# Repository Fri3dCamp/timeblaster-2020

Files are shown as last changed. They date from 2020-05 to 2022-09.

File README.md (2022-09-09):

# Time Blaster

This repository contains the design files for the Time Blaster project part of Fri3d Camp 2020.

The design is based around an ATMega328p, some IR receivers and an IR LED.

The progress of this project can be followed on [Hackaday.io](https://hackaday.io/project/167668-time-blaster)

## Blockdiagram

In order to make the documentation easier to use, we've added the block diagram as well.

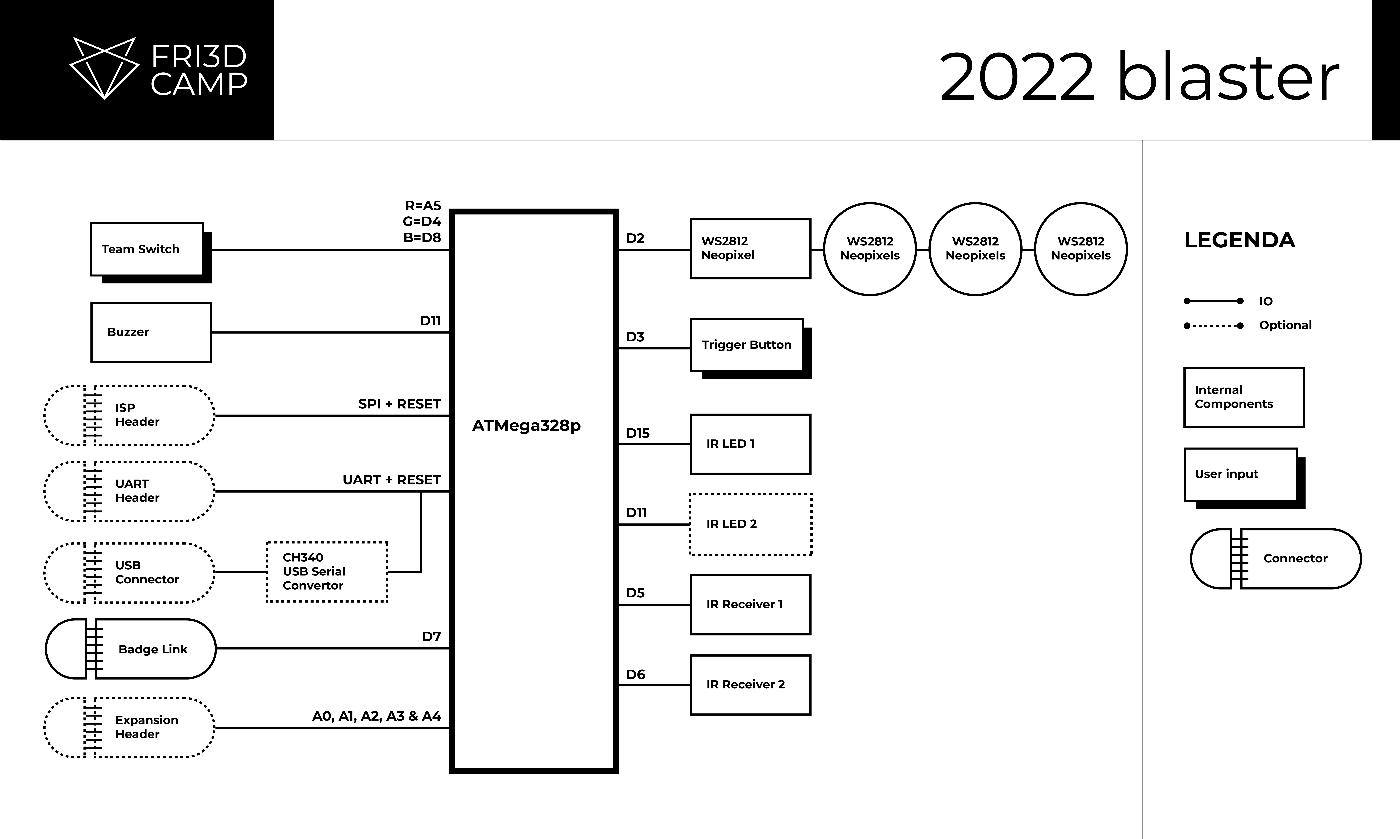
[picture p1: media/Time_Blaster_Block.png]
Time Blaster Block Diagram


## Hardware Revision 00

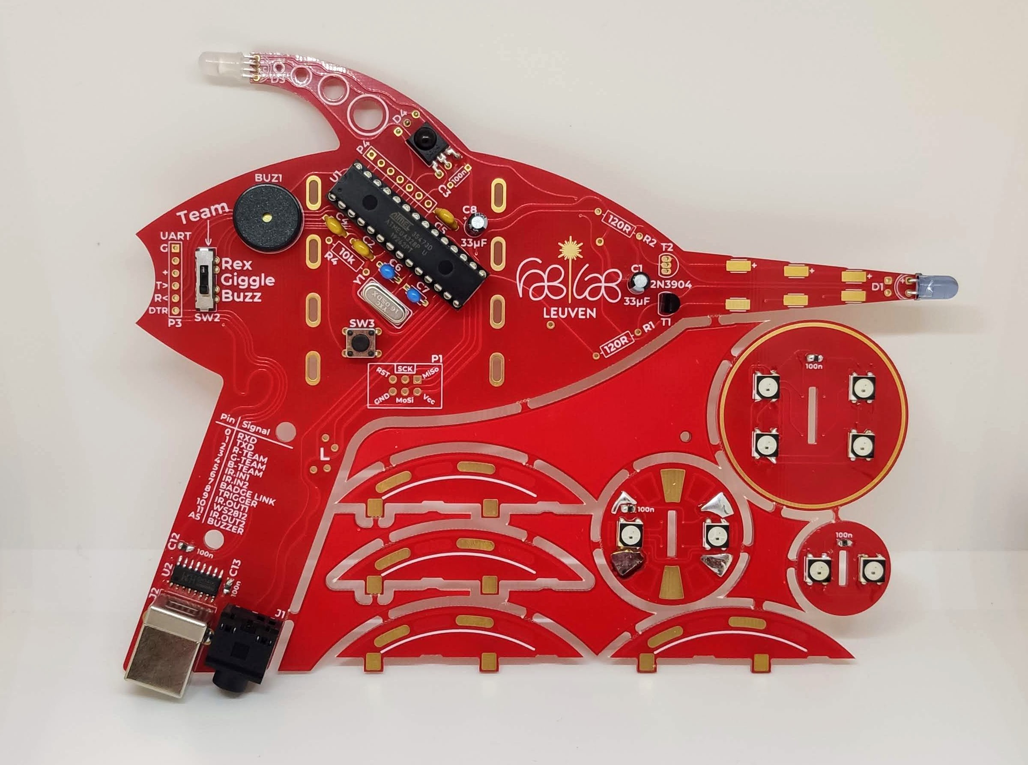
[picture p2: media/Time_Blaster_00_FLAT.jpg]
Time Blaster 00 Flat


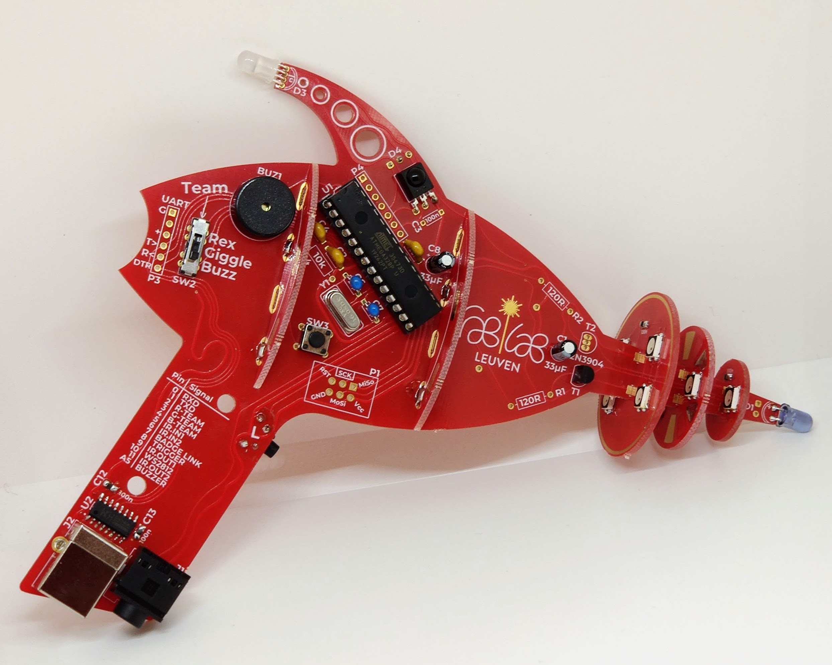
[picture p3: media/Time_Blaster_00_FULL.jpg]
Time Blaster 00 Full


## Hardware Revision 01

Added support for USB C and Micro USB. Fixed a bug with the USB Serial convertor, some pin swaps for firmware development.

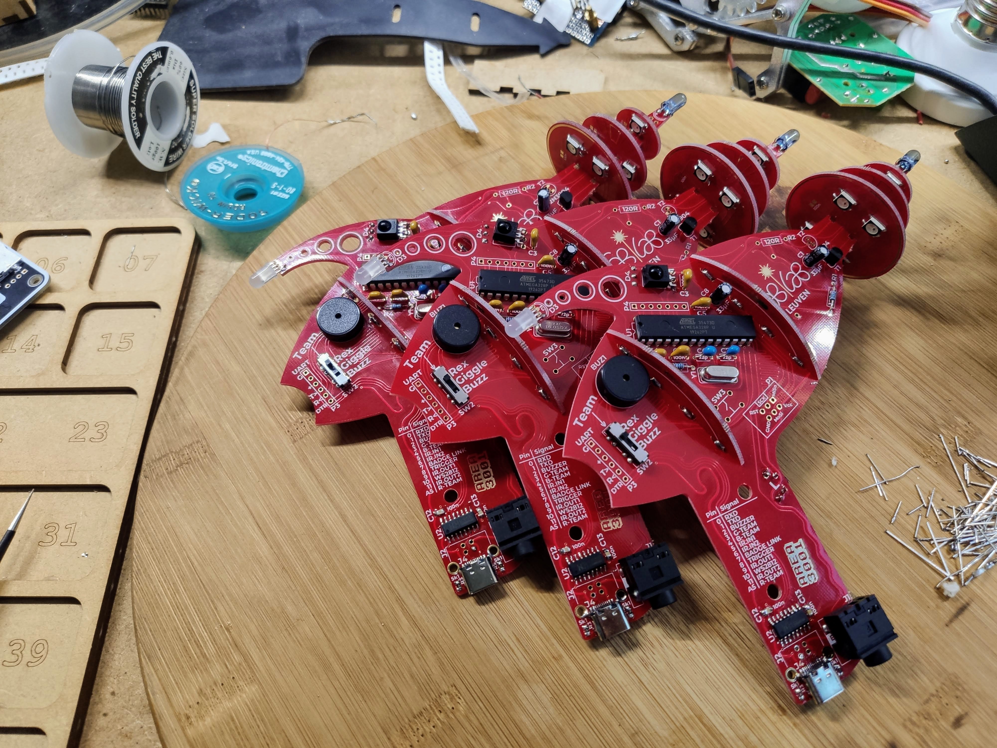
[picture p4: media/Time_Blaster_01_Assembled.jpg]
Time Blaster 01 Assembled


## Hardware Revision 02

Added a series resistor for the IR LEDs, this is only required when powering the device from 5V.

## Firmware

The default firmware (which has already been flashed on the MCU) can be found on the [Area 3001 Github page](https://github.com/area3001/Timeblaster).

# Assembly Instructions
The assembly instructions can also be found in the leaflets located in the "media" folder of this repository

## Resistor note
The 120Ω resistor has been marked with a red permanent marker since the color coding for the 120Ω and 10KΩ resistor are too similar

## Trigger switch
The side of the trigger switch can be chosen depending on left hand or right hand use case

## Team selection switch
Take note of silkscreen on the PCB for correct placement of the team selector switch. The switch has metal on 1 side, this side is also indicated on the PCB and should face the team names.

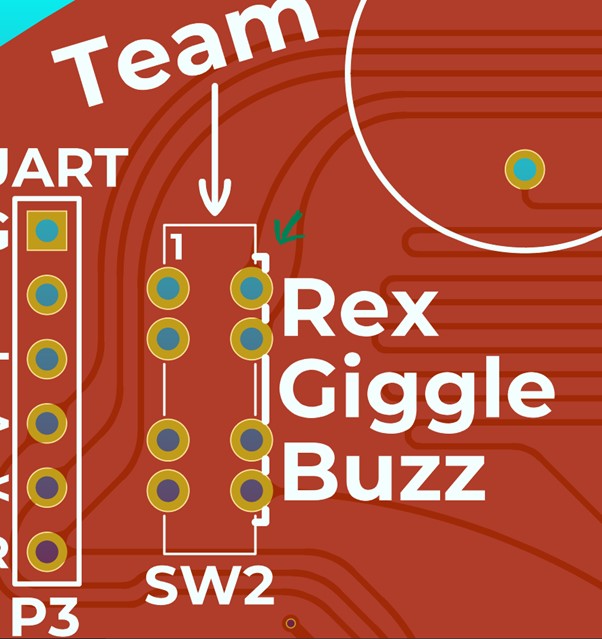
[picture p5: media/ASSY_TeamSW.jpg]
Time Blaster Assembly Team Switch Render


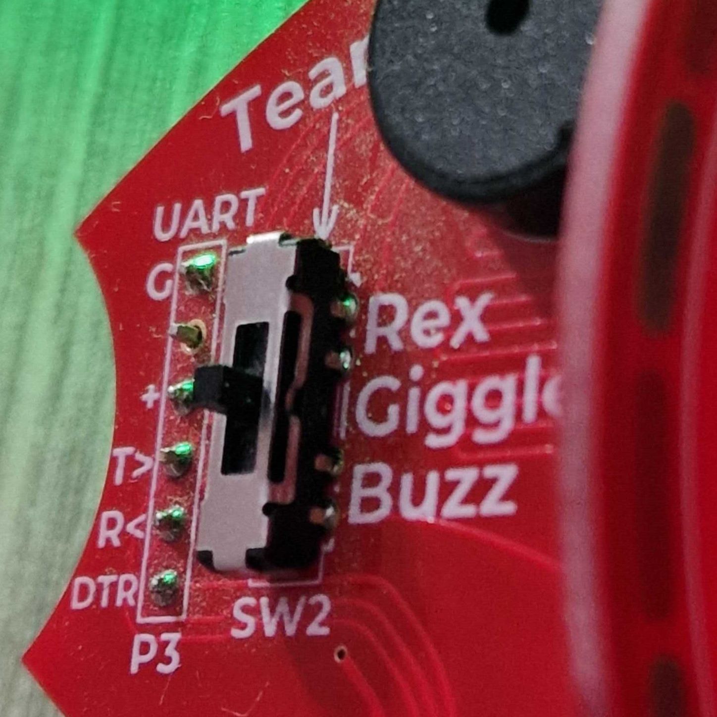
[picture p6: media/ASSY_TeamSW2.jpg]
Time Blaster Assembly Team Switch

 
## Microcontroller soldering note
Take care when mounting the ATMega328p microcontroller, don't heat up the pins too long to avoid damaging them. To avoid creating a hot spot, you can opt for alternating sides when soldering the pins.

## Ring mounting
Mount the rings with SMD LEDs before you solder the IR LED in place.

## LED Polarity
The IR LED has a small + polarity marking on the board, this is the hole for the long lead of the LED.

## Which components to mount
R1 120Ω, MOSFET T1, R6 33Ω and IR LED D1 should be mounted 

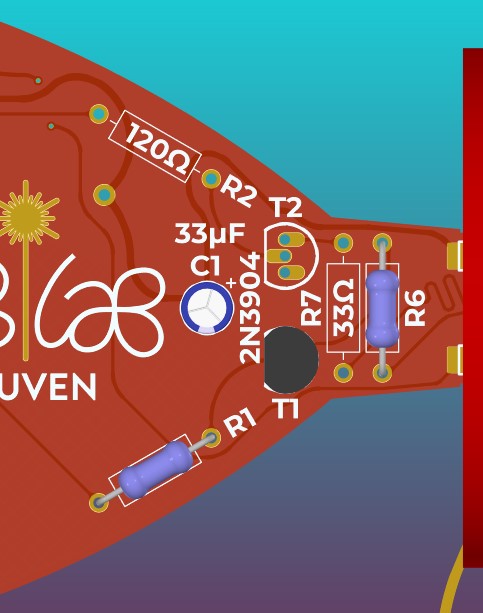
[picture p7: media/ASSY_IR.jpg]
Time Blaster Assembly IR

 
Capacitor C4 (100nF), push button SW3 and right angle connector P3 are optional for Arduino style programming over FTDI UART connection.

## USB
Optional USB circuitry kits based around the CH340 USB to serial convertor are available upon request. These kits include an USB connector (USB-B, USB-C or Micro USB), 2 capacitors and the CH340 chip. In case of the USB-C variant, there will also be 2 resistors of 5.1kΩ included.

# 3D Printable grip
Thomas Pilkington designed a 3D printable grip for the blaster which vastly improves the ergonomics of the blaster, especially for adults. These files can either be printed as-is or modified to your preference. The model contains cutouts for both left- and righthanded triggers and for the optional USB-B or USB-C connector. The guys from [KO-LAB](https://ko-lab.space/) slightly modified the design for better clearance, these v2 files can also be found in the grip directory.

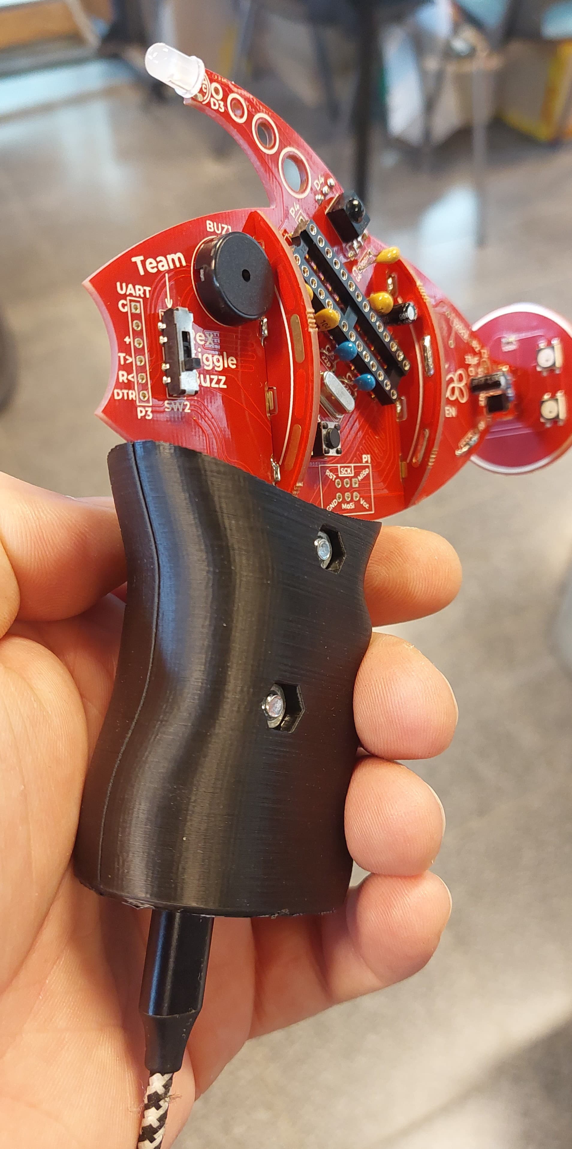
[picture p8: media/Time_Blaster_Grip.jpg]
Time Blaster with grip


# 3D Printable LED Protector
[Hans Polders](https://github.com/melazarus) designed a 3D printable IR LED protector so that it has less chance of bending and breaking.
It was designed in [OpenSCAD](https://openscad.org/), for which the source file is also available.

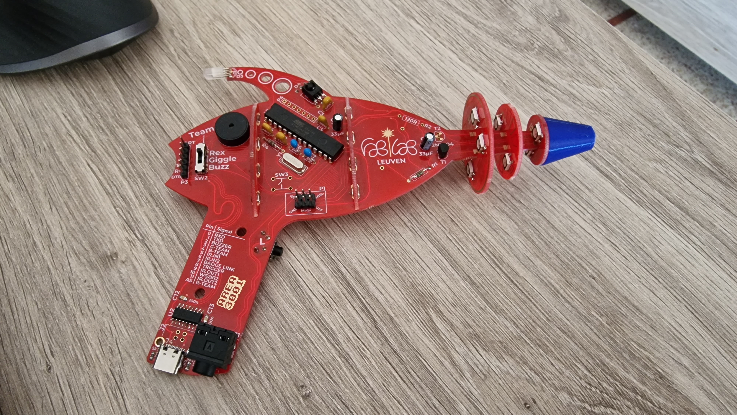
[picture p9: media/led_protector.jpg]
LED Protector

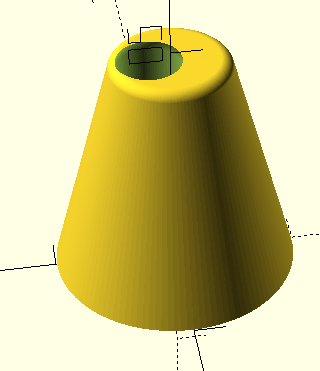
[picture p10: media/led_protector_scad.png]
LED Protector SCAD


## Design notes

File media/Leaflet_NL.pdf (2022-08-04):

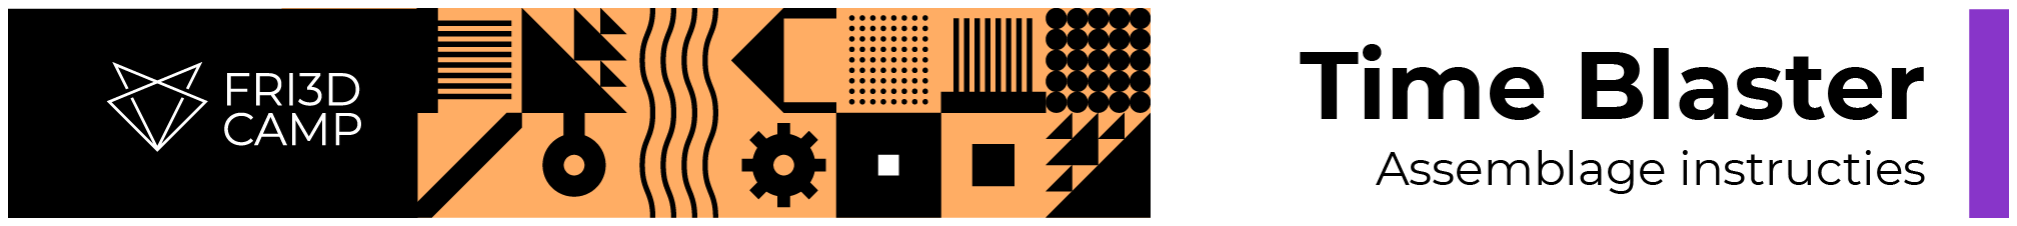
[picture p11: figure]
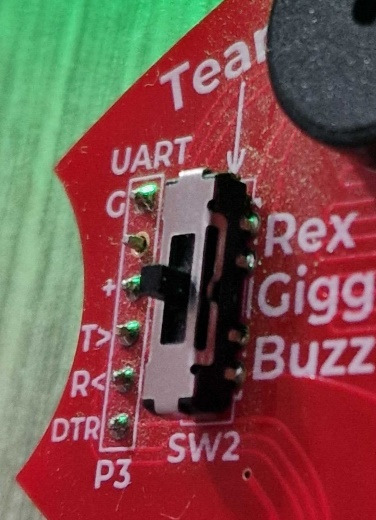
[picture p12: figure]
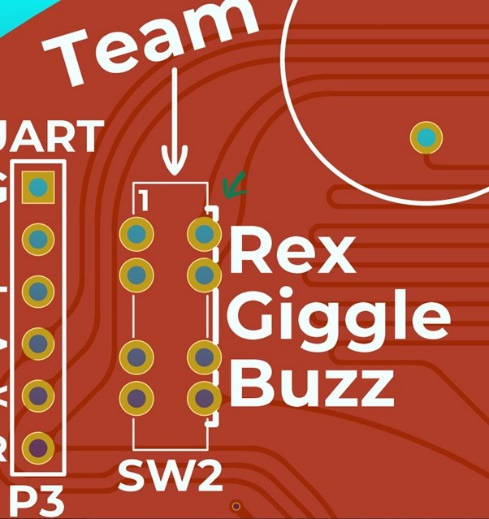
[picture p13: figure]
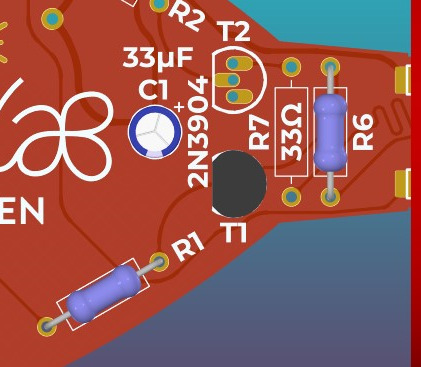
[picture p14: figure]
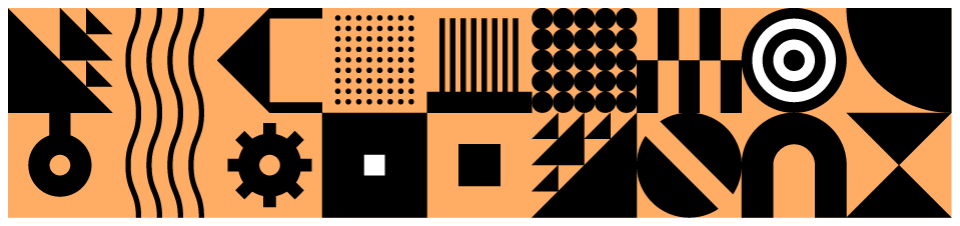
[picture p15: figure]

Wim Van Gool – 20220725 – Blaster NL Rev.02 https://github.com/Fri3dCamp/timeblaster-2020https://hackaday.io/project/167668-time-blasterhttps://fri3d.be/badge/

Inhoud
In de verpakking van de Time Blaster zal je deze handleiding, een printplaat, een kabel om de Blaster aan de badge aan te sluiten en een zakje boordevol componenten vinden. Ontbreekt een van deze zaken? Aarzel dan niet om even te informeren bij de infodesk.

Voor enkele van deze componenten is wat extra uitleg wel handig, vandaar deze handleiding.

“Rode” Weerstand
De 120Ω-weerstand is gemarkeerd met een rode permanent marker om verwarring te voorkomen aangezien de kleurcodes voor de 120Ω en 10KΩ gelijkaardig zijn.

“Trigger”-drukknop
Afhankelijk of je links- of rechtshandig
bent, kan je de drukknop SW1 aan de
correcte zijde van de printplaat monteren. Let hiervoor op de “L” of “R”.

Selectieschakelaar “Team”
Kijk goed naar de markering op de printplaat om de schakelaar correct te monteren. De schakelaar heeft een metalen lip aan 1 zijde. Deze zijde moet
richting de teamnamen staan.

!Soldeertip! Microcontroller
Wanneer je de ATMega328p-microcontroller gaat solderen zorg je er best voor dat de pinnen niet te lang warm zijn (om te voorkomen dat je deze component zou beschadigen). Uiteraard moet je nog wel een mooie uitvloeiing hebben van het soldeersel voor een correcte verbinding. Een optie om de hitte wat te verspreiden is het alternerend solderen van pinnen aan beide zijden.

Zorg dat je deze component correct oriënteert. Dit kan je zien aan de kleine U-vormige uitsparing op de chip die ook getekend is op de printplaat.

Welke componenten moet je solderen?
!Let op! Vooraan op de Blaster zijn er enkele
componenten die er 2x op staan. Transistor T1, IR LED D1, Weerstanden R1 120Ω en R6 33Ω moeten gesoldeerd worden. Zoals in de afbeelding hiernaast. T2, D2, R2 en R7 dienen niet bestukt te worden.

Verder zijn er ook nog optionele componenten: condensator C4 (100nF), drukknop SW3 en haakse connector P3. Deze zorgen ervoor dat je kan programmeren met de Arduino IDE via een FTDI UART kabel.

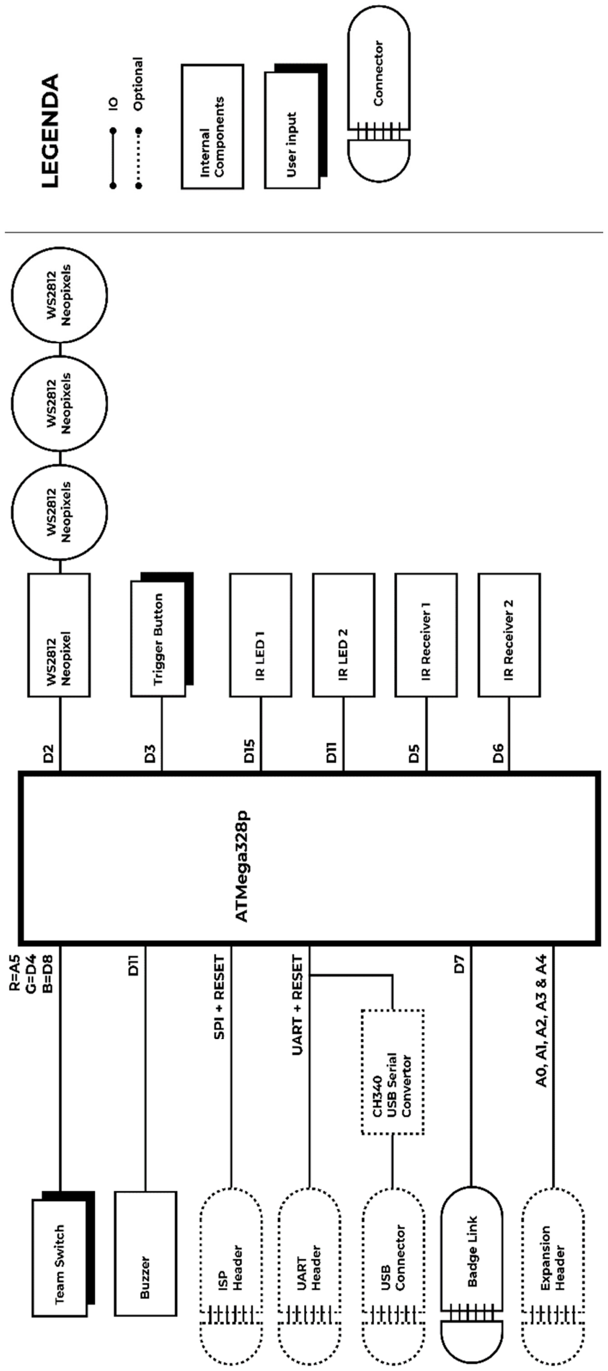
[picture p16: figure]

Ringen solderen
Soldeer de LED-ringen alvorens je de infrarood LED vooraan
monteert. Let op dat de LEDs niet naar voor gericht zijn en dat de “+” markering overeen komt.

Polariteit
De infrarood-LED heeft een kleine “+” markering op de printplaat. Dit is het gat voor het lange beentje van deze LED. Dit geldt ook voor de

### 2 grote condensatoren van 33µF (C1

en C8). Hierbij is het ook belangrijk dat het lange beentje in het gat gaat met de “+” aanduiding.

Optionele USB Interface
De extra componenten voor het optionele USB circuit zijn beschikbaar op aanvraag. De kit bestaat uit een CH340 USB naar serieel omvormer, een USB
connector (USB-B, USB-C of Micro USB)en 2 condensators. In het geval van de USB-C variant zullen er ook 2 weerstanden van 5.1kΩ bij zitten. Om deze kit te laten werken is condensator C4 een vereiste. Let op, je mag de USB interface niet aansluiten wanneer de badge nog verbonden is om beschadiging aan de badge te voorkomen. Deze USB interface is vooral gemaakt om zelf de firmware te kunnen updaten of om er een standalone Blaster van te maken gevoed door een power bank.

Solderen?
Heb je zelf geen soldeerbout bij of hulp nodig tijdens het solderen spring dan zeker even binnen in de Dekimo soldeerhoek!

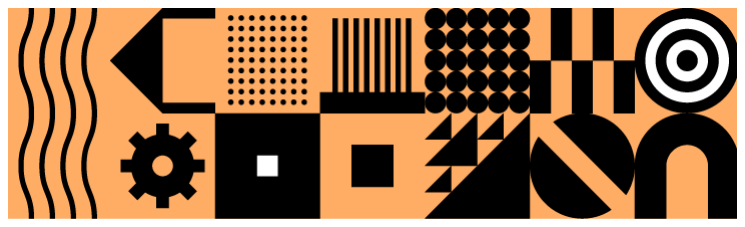
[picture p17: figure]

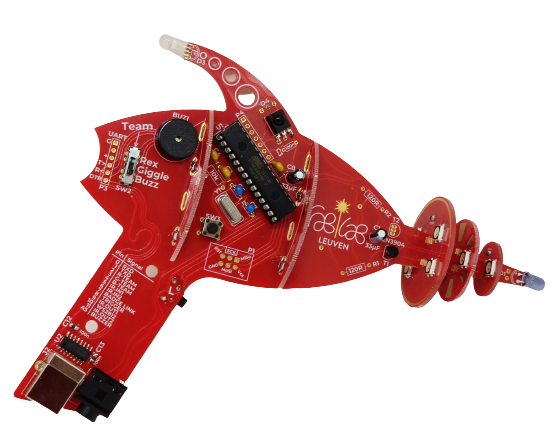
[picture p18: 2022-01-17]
media/Time_Blaster_00_FULL_noBG.png

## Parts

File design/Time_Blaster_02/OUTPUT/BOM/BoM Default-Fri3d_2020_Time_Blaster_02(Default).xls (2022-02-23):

Bill of Materials |  |  | Time Blaster
Project: |  | Fri3d_2020_Time_Blaster_02.PrjPcb
Revision: |  | 02
Variant: |  | Default
Creation Date: | 02/01/2022 | 14:20
Print Date: | 2022-01-02 | 14:20:59
Footprint | Comment | LibRef | Designator | Value | Description | Supplier 1 | Supplier Part Number 1 | Supplier 2 | Supplier Part Number 2 | Supplier 3 | Supplier Part Number 3 | Quantity
CUI_CEP-1162 | 14x14x7mm Piezo Buzzer Transducer 80dB | BUZ CUI CEP-1162 | BUZ1 | CMT-1203-SMT | BUZ CUI CEP-1162 | Digi-key | 102-1134-ND | LCSC | C360604 |  |  | 1
C_4x7_1.5mm | CAP_POL | CAP 13uF 16V 4x7 | C1, C8 | 33uF 16V | Capacitor electrolyt | LCSC | C3314 |  |  |  |  | 2
C_5.08mm |  | CAP 100nF 50V 5.08mm | C2, C3, C4, C5 | 100nF 50V | CAP 100nF 50V 5.08mm | LCSC | C84772 |  |  |  |  | 4
C_5.08mm |  | CAP 22pF 50V 5.08mm | C6, C7 | 22pF 50V | CAP 22pF 50V 5.08mm | LCSC | C263190 |  |  |  |  | 2
LED_5MM_RD | 5mm IR LED, 940nm, 100mA, 1.35V, 25Deg | LED IR 5mm TSAL6400 | D1 | TSAL6400 | LED IR 5mm TSAL6400 | Farnell | 3152868 |  |  |  |  | 1
LED_5mm_RGB | WS2812 based digital RGB LED 5mm | LED RGB WS2812 5mm | D3 | WS2812D-F5 | LED RGB WS2812 5mm | LCSC | C190565 |  |  |  |  | 1
VIS_TSOP381x_BENT | IRM-3638N3F14 Infrared Receiver 38 kHz 45° 2.7-5.5V | PHO IR Rx RA | D4, D5 | IRM-3638N3F14 | PHO IR Rx RA | LCSC | C264262 |  |  |  |  | 2
LED_5050_WS2812B_BLACK | WS2812 based digital RGB LED 5050 Black package | LED # RGB WS2812B-5050 BL | D6, D7, D8, D9, D10, D11, D12, D13 | WS218B 5050 BL | LED # RGB WS2812B-5050 BL | Aliexpress | WS2812B Black 5050 | LCSC | C114586 |  |  | 8
CUI_SJ1-3525NG | 3.5mm jack, dual switch, black, 3 contacts | AUDIO JACK 3.5 3c SJ1-3525NG | J1 | SJ1-3525NG | AUDIO JACK 3.5 3c SJ1-3525NG | Digi-key | CP1-3525NG-ND |  |  |  |  | 1
SOLDER_SW_V_1MM | Easy to solder connection | SOLDER SW V 1MM | P2 | NO BOM | SOLDER SW V 1MM |  |  |  |  |  |  | 1
HDR1X6 | Header 6 | Pin Header 2.54mm 6way | P3 |  | Pin Header 2.54mm 6way |  |  |  |  |  |  | 1
RES_10mm |  | RES 120R 1/4W | R1 | 120R | RES 120R 1/4W | LCSC | C58684 |  |  | Generic | 120R 1/4W 1% TH 10mm | 1
RES_10mm |  | RES 10k 1/4W | R4 | 10k | RES 10k 1/4W | LCSC | C58673 |  |  | Generic | 10k 1/4W 1% TH 10mm | 1
RES_10mm |  | RES 33R 1/4W | R6 | 33R | RES 33R 1/4W | LCSC | C173006 |  |  | Generic | 33R 1/4W 1% TH 10mm | 1
TACTSW_RA_385 | Tact switch, RA, 3,85mm | SW TACT RA 3,85mm 431256038716 | SW1 | 431256038716 | SW TACT RA 3,85mm 431256038716 | Wurth | 431256038716 | Mouser | 710-431256038716 |  |  | 1
CK_JS203011CQN | Slide switch dual pole triple throw | SW Slide DP3T C&K JS203011CQN | SW2 | JS203011CQN | SW Slide DP3T C&K JS203011CQN | Digi-key | 401-2004-ND | LCSC | K3-2336D-F1 |  |  | 1
TO-92A _EASY | 0.2A 40V 100hfe NPN Transistor | 2N3904 NPN 0.2A | T1 | 2N3904 | 2N3904 NPN 0.2A | Farnell | 1700648 | LCSC | C118538 |  |  | 1
DIP_N_28 | 8-bit MCU | AVR ATMega 328p MCU PDIP | U1 | ATMega 328p | AVR ATMega 328p MCU PDIP | LCSC | C33901 | Mouser | 556-ATMEGA328P-PU |  |  | 1
HC49US | 16MHz 18pF HC49US | XTAL 16Mhz HC49US | Y1 | 16MHz | XTAL 16Mhz HC49US | Farnell | 2508458 | LCSC | C16212 |  |  | 1
 |  |  |  |  |  |  |  |  |  |  |  | 32
Approved |  | Notes

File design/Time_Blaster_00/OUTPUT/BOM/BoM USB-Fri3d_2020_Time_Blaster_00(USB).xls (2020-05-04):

Bill of Materials |  |  | Time Blaster
Project: |  | Fri3d_2020_Time_Blaster_00.PrjPcb
Revision: |  | 00
Variant: |  | USB
Creation Date: | 09/12/2019 | 19:33
Print Date: | 2019-12-09 | 19:36:32
Footprint | Comment | LibRef | Designator | Value | Description | Supplier 1 | Supplier Part Number 1 | Supplier 2 | Supplier Part Number 2 | Quantity
CUI_CEP-1162 | 14x14x7mm Piezo Buzzer Transducer 80dB | BUZ CUI CEP-1162 | BUZ1 | CMT-1203-SMT | BUZ CUI CEP-1162 | Digi-key | 102-1134-ND | LCSC | C360604 | 1
C_4x7_1.5mm |  | CAP 13uF 16V 4x7 | C1, C8 | 33uF 16V | CAP 13uF 16V 4x7 | LCSC | C3314 |  |  | 2
C_5.08mm |  | CAP 100nF 50V 5.08mm | C2, C3, C4, C5 | 100nF 50V | CAP 100nF 50V 5.08mm | LCSC | C84772 |  |  | 4
C_5.08mm |  | CAP 22pF 50V 5.08mm | C6, C7 | 22pF 50V | CAP 22pF 50V 5.08mm | LCSC | C263190 |  |  | 2
C0805_N |  | CAP # 100nF 16V 0805 | C12, C13 | 100nF 16V | CAP # 100nF 16V 0805 |  |  |  |  | 2
LED_5MM_RD | 5mm IR LED, 940nm, 100mA, 1.35V, 25Deg | LED IR 5mm TSAL6400 | D1 | TSAL6400 | LED IR 5mm TSAL6400 | Farnell | 3152868 |  |  | 1
LED_5mm_RGB | WS2812 based digital RGB LED 5mm | LED RGB WS2812 5mm | D3 | WS2812D-F5 | LED RGB WS2812 5mm | LCSC | C190565 |  |  | 1
VIS_TSOP381x_BENT | IRM-3638N3F14 Infrared Receiver 38 kHz 45° 2.7-5.5V | PHO IR Rx RA | D4, D5 | IRM-3638N3F14 | PHO IR Rx RA | LCSC | C264262 |  |  | 2
LED_5050_WS2812B_BLACK | WS2812 based digital RGB LED 5050 Black package | LED # RGB WS2812B-5050 BL | D6, D7, D8, D9, D10, D11, D12, D13 | WS218B 5050 BL | LED # RGB WS2812B-5050 BL | Aliexpress | WS2812B Black 5050 |  |  | 8
CUI_SJ1-3525NG | 3.5mm jack, dual switch, black, 3 contacts | AUDIO JACK 3.5 3c SJ1-3525NG | J1 | SJ1-3525NG | AUDIO JACK 3.5 3c SJ1-3525NG | Digi-key | CP1-3525NG-ND |  |  | 1
WE_61400416121 | Vertical USB B 61400416121 | USB B VERTICAL 61400416121 | J2 | 61400416121 | USB B VERTICAL 61400416121 | Farnell | 1642035 | LCSC | C46392 | 1
RES_10mm |  | RES 120R 1/4W | R1 | 120R | RES 120R 1/4W | LCSC | C58684 |  |  | 1
RES_10mm |  | RES 10k 1/4W | R4 | 10k | RES 10k 1/4W | LCSC | C58673 |  |  | 1
TACTSW_RA_385 | Tact switch, RA, 3,85mm | SW TACT RA 3,85mm 431256038716 | SW1 | 431256038716 | SW TACT RA 3,85mm 431256038716 | Wurth | 431256038716 | Mouser | 710-431256038716 | 1
CK_JS203011CQN | Slide switch dual pole triple throw | SW Slide DP3T C&K JS203011CQN | SW2 | JS203011CQN | SW Slide DP3T C&K JS203011CQN | Digi-key | 401-2004-ND | LCSC | K3-2336D-F1 | 1
TO-92A | 0.2A 40V 100hfe NPN Transistor | 2N3904 NPN 0.2A | T1 | 2N3904 | 2N3904 NPN 0.2A | Farnell | 1700648 | LCSC | C118538 | 1
DIP_N_28 | 8-bit MCU | AVR ATMega 328p MCU PDIP | U1 | ATMega 328p | AVR ATMega 328p MCU PDIP | LCSC | C33901 | Mouser | 556-ATMEGA328P-PU | 1
SOIC_N_16 | USB to full UART with internal crystal | CH340C # UCB UART | U2 | CH340C | CH340C # UCB UART | LCSC | C84681 |  |  | 1
HC49US | 16MHz 18pF HC49US | XTAL 16Mhz HC49US | Y1 | 16MHz | XTAL 16Mhz HC49US | Farnell | 2508458 | LCSC | C16212 | 1
 |  |  |  |  |  |  |  |  |  | 33
Approved |  | Notes

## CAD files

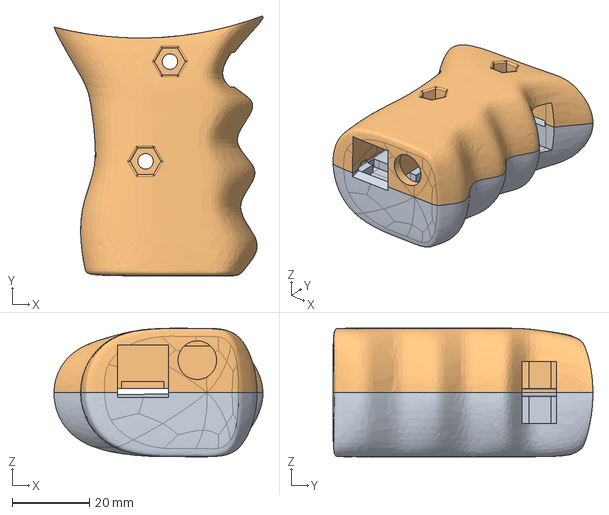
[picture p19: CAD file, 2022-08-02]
grip/Fri3d-TimeBlaster-Grip_v2.step
54.1 x 67.3 x 33.3 mm

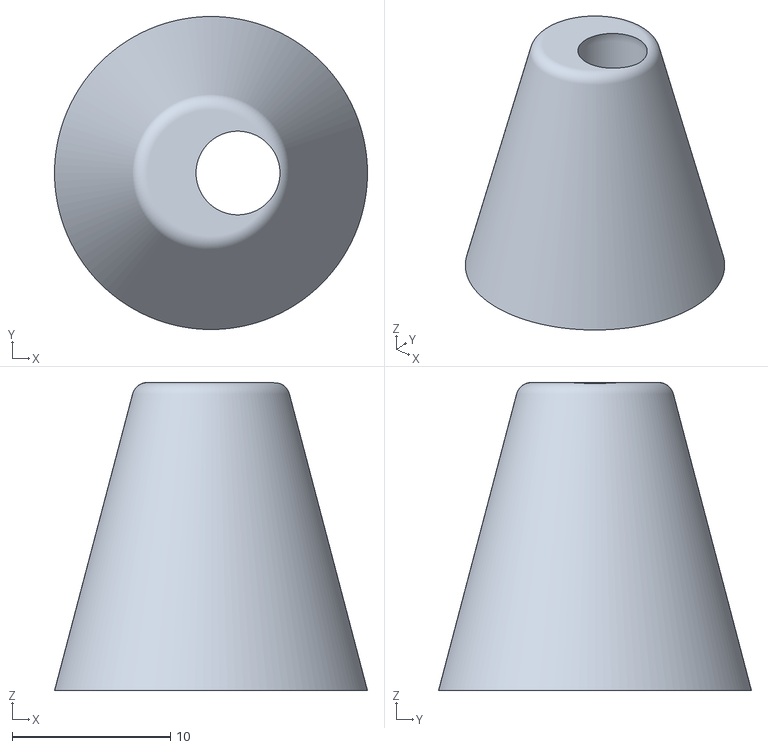
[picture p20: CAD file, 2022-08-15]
led_protector/Led_protector.stl
19.8 x 19.8 x 19.5

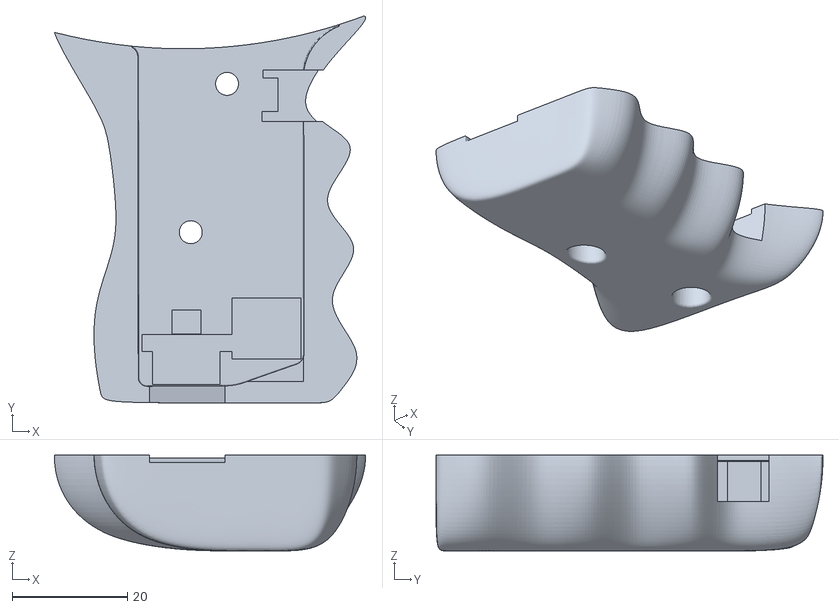
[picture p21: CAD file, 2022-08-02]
grip/Fri3d-TimeBlaster-Grip_v2_Left.stl
54.1 x 67.3 x 16.7

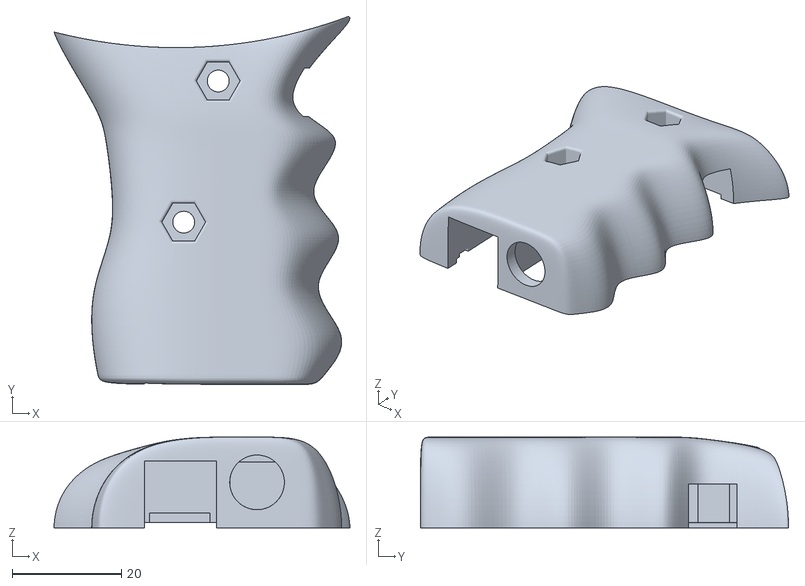
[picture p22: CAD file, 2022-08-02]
grip/Fri3d-TimeBlaster-Grip_v2_Right.stl
54.1 x 67.3 x 16.6

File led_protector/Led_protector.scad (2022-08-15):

$fn = 120;

difference(){  
  translate([0,0,19/2-.5])
    minkowski(){
      cylinder(19,d1=20-2,d2=10-2,center=true);
      sphere(d=2);
    }

  union(){
    translate([1.7,0,12.5])
      union(){
        translate([0,0,9-(5.5/2)])
          sphere(d=5.5);
        cylinder(9-(5.5/2),d=5.5);
        cylinder(1.2,d=6.5);
        
        translate([0,0,-19])
        cylinder(20,d=6.5);
        
        translate([-0.5,-0.5+(2.54/2),-3])
          cube([1,1,3]);
        translate([-0.5,-0.5-(2.54/2),-3])
          cube([1,1,3]);
      }
        translate([0,0,12.5/2-.01])
          intersection(){
            cylinder(12.5,d1=8,d2=5.5,center=true);
            cube([2.5,8,13],center=true);
          }
  }
  translate([0,0,-1.5]){
    cube([20,20,3],center=true);
  }
}

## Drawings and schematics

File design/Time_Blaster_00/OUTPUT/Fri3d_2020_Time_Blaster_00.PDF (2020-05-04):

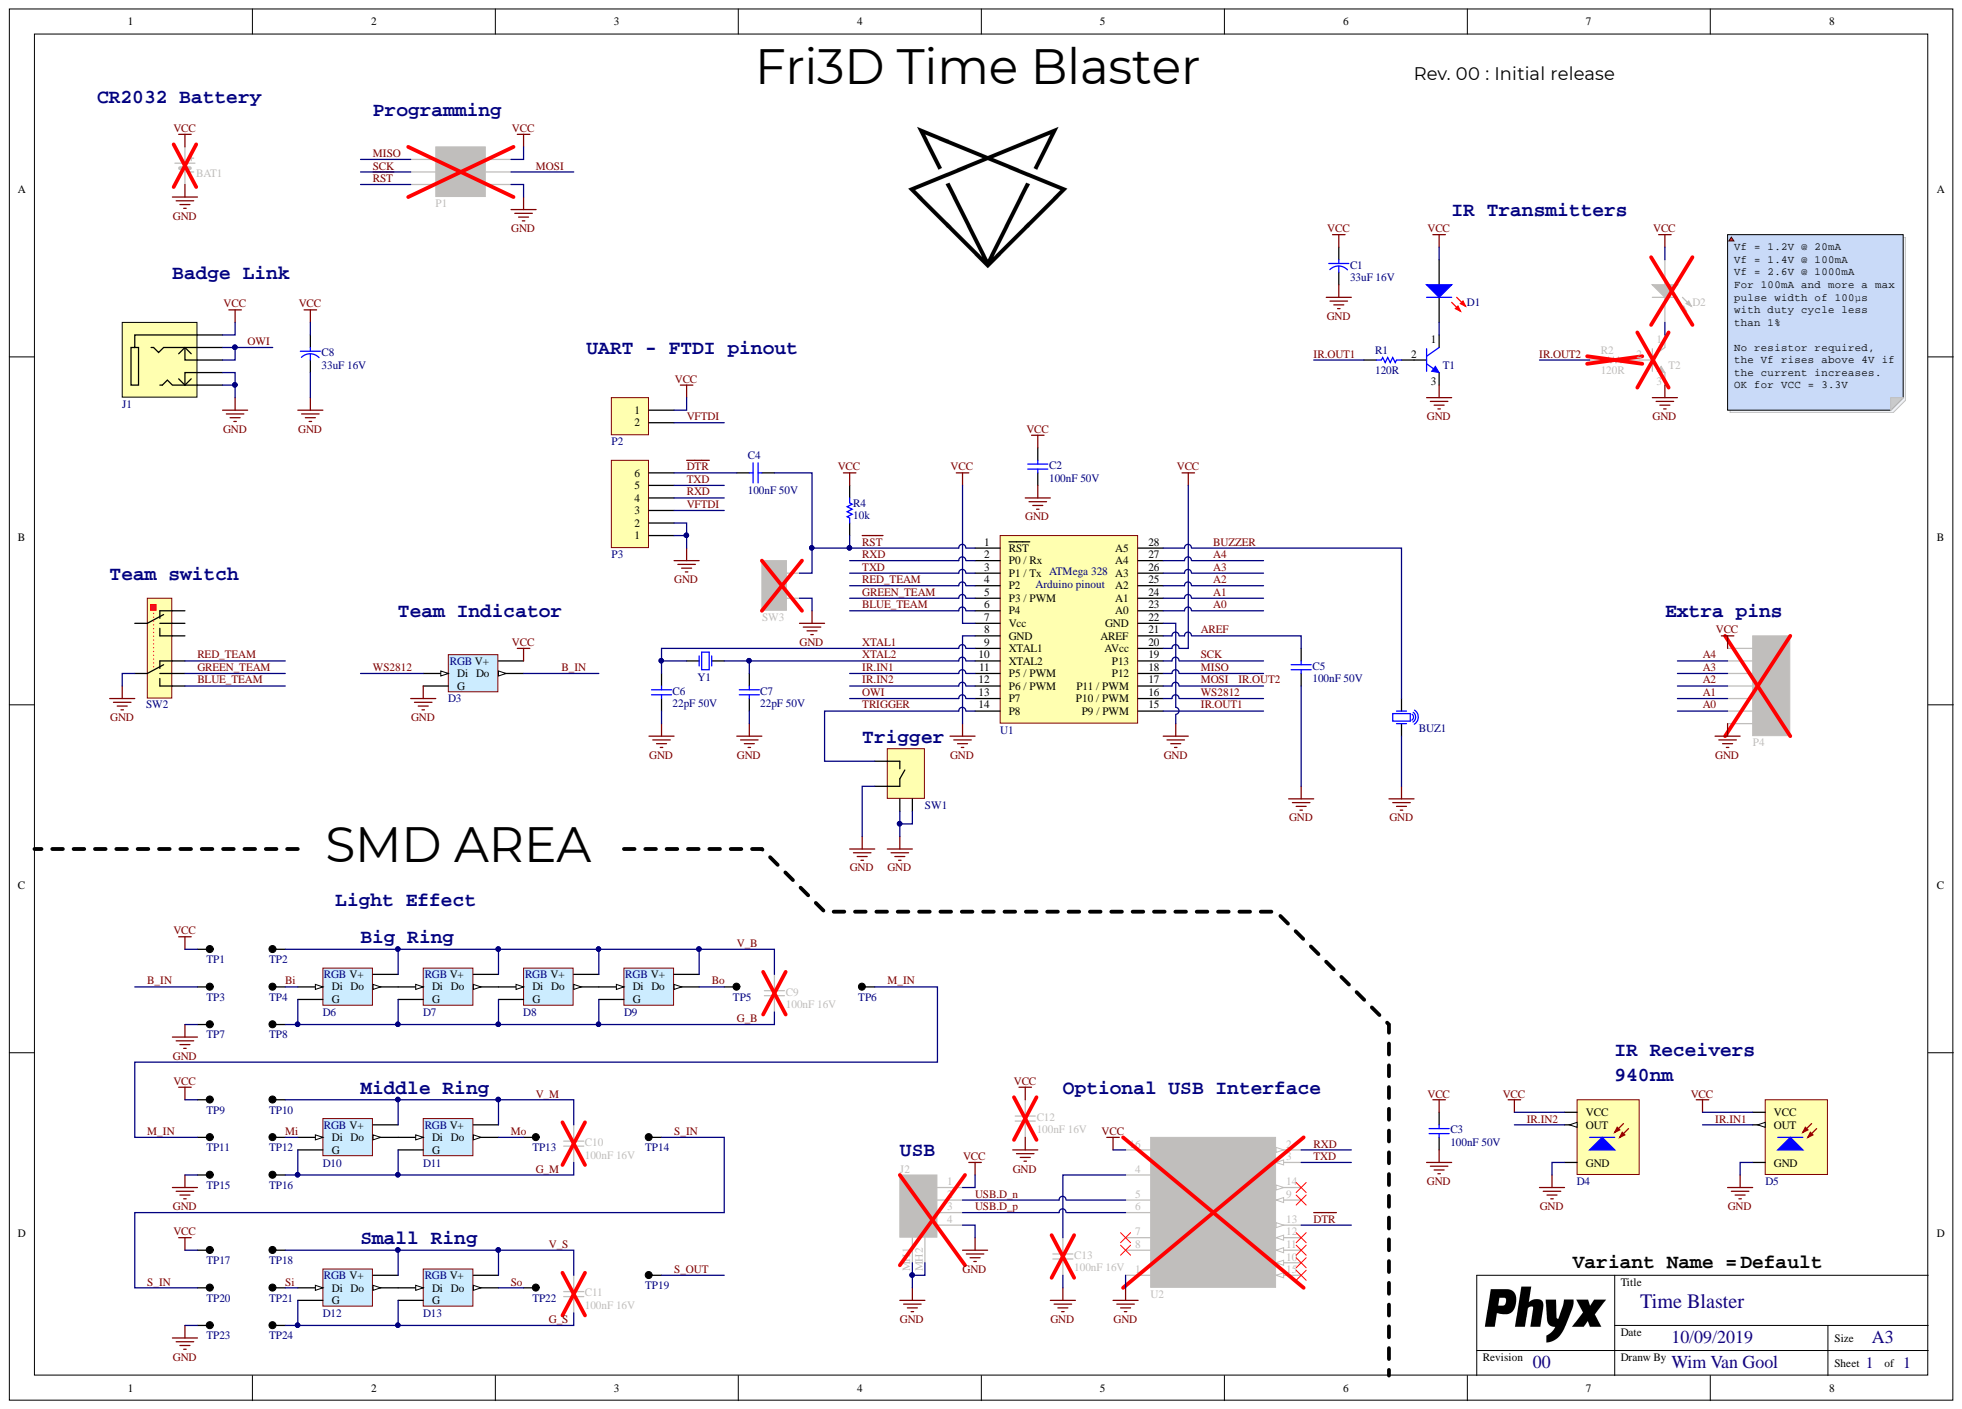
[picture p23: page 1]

For 100mA and more a max
pulse width of 100µs
with duty cycle less
than 1%

No resistor required,
the Vf rises above 4V if
the current increases.
OK for VCC = 3.3V

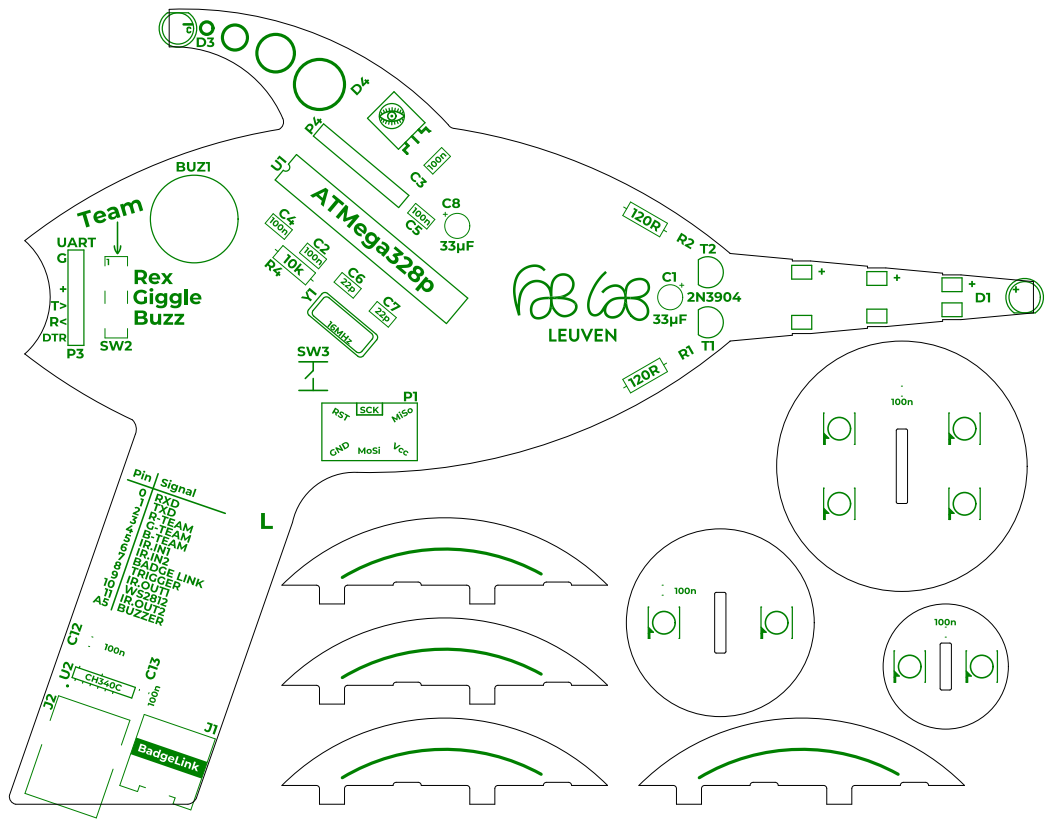
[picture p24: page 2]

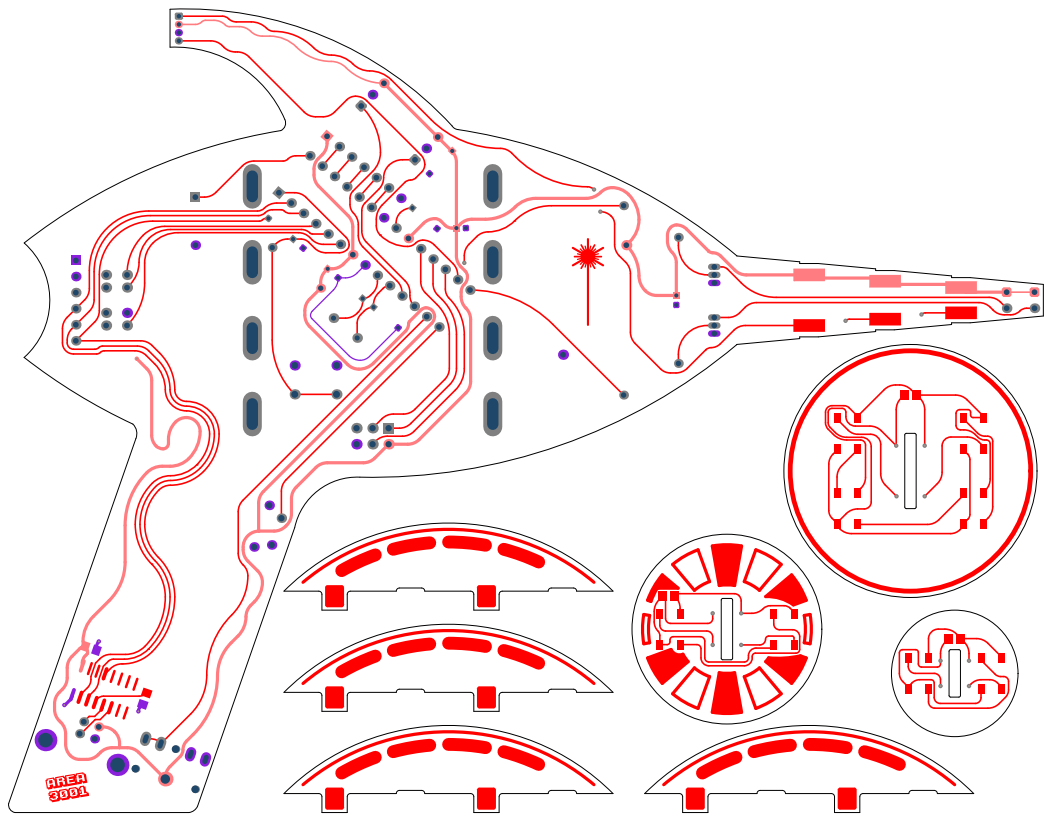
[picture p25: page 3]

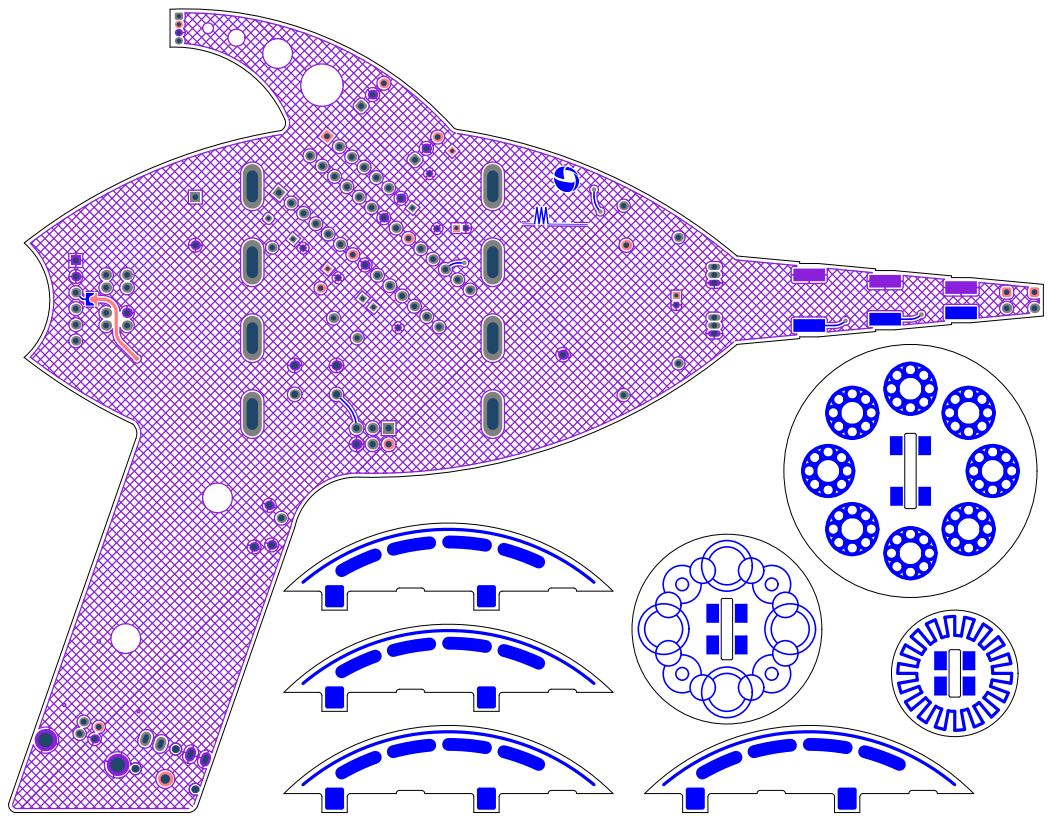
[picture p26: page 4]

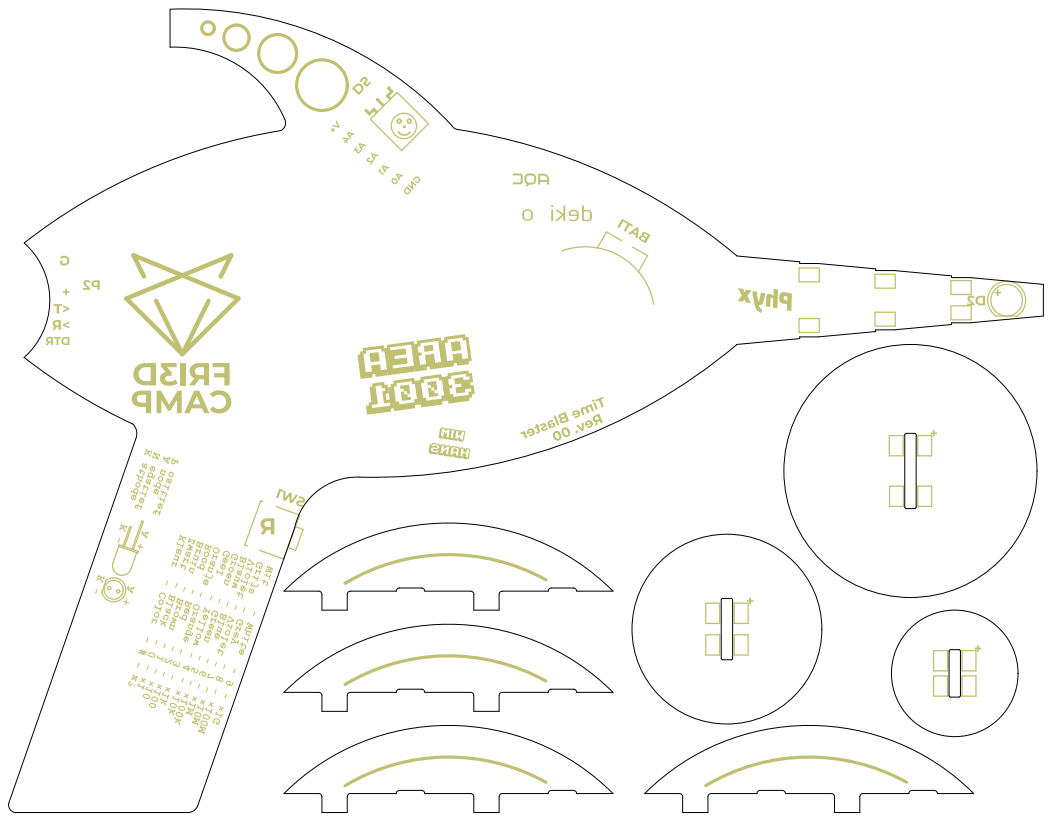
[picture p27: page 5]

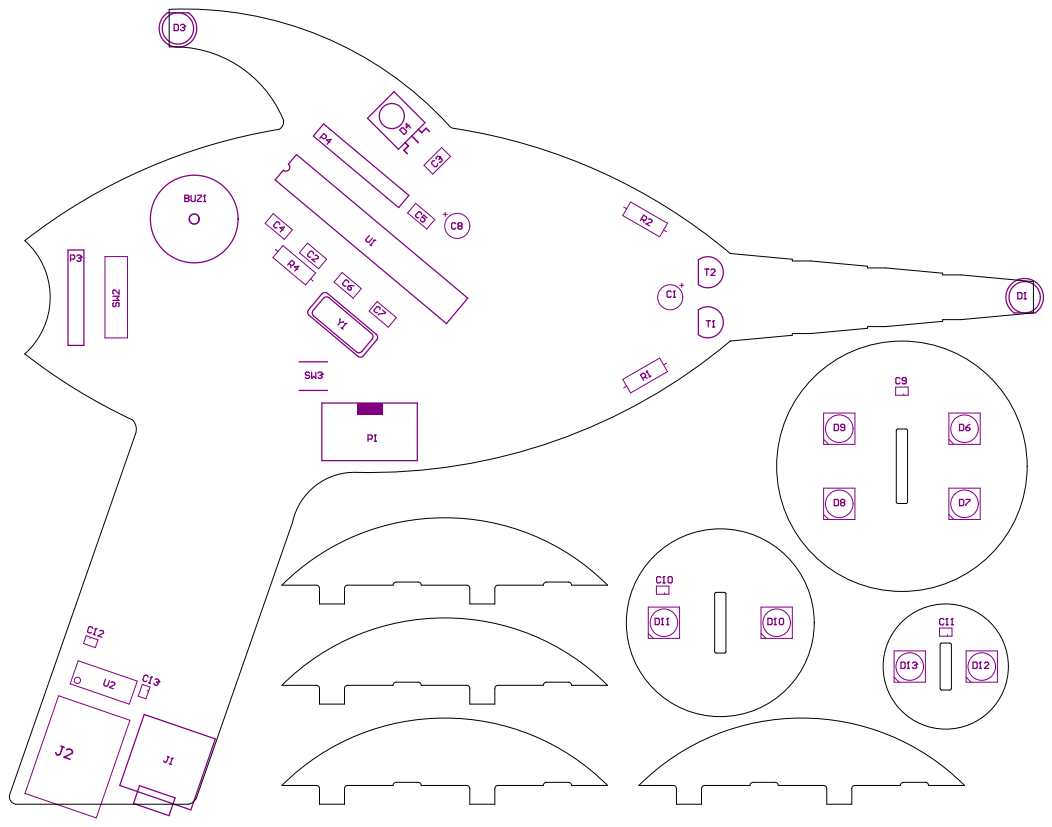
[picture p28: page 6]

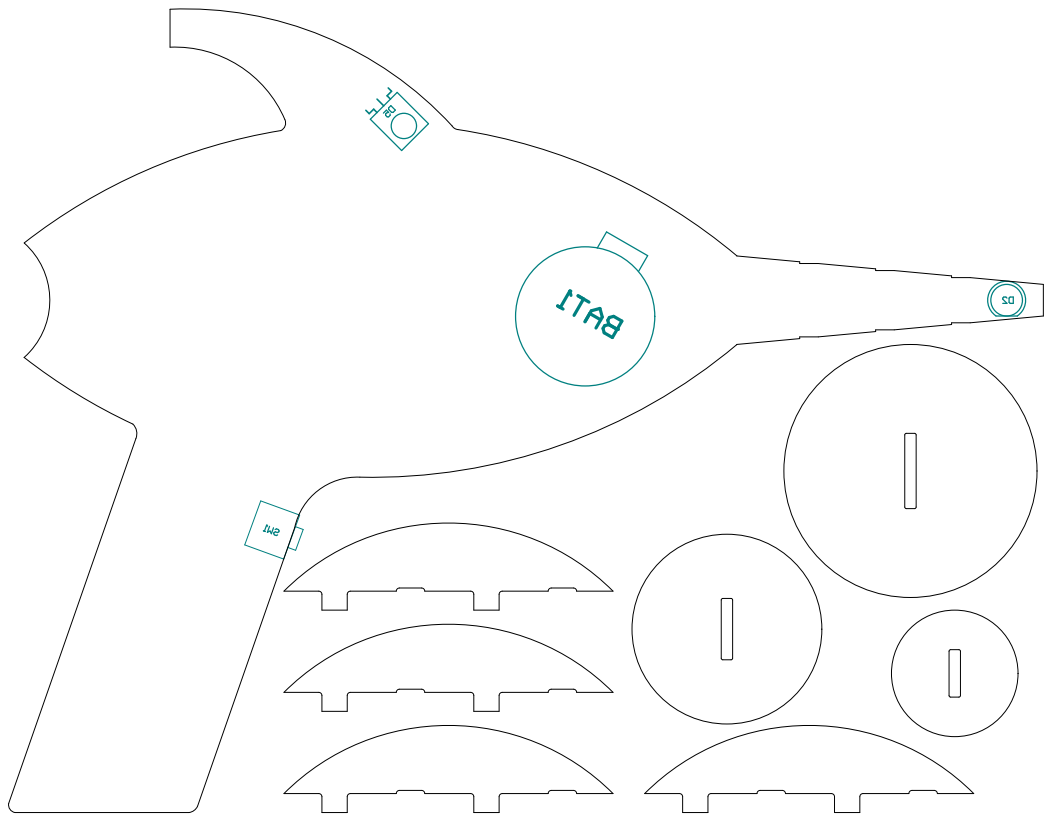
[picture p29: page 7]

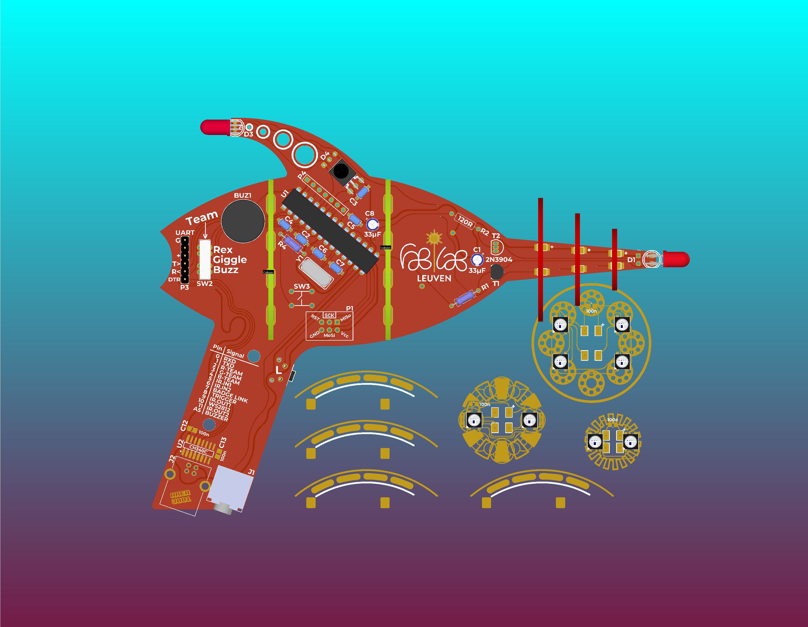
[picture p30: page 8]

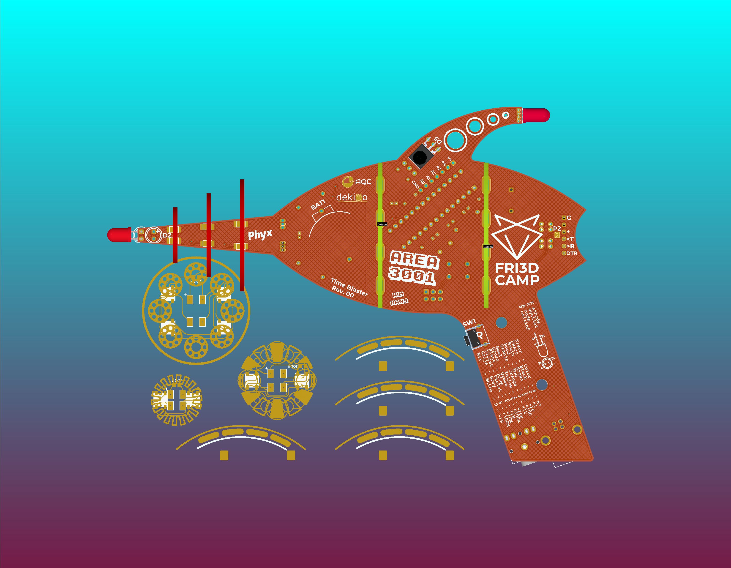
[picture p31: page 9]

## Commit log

2020-05-04 Initial commit
    Initial commit of version 00 and 01
    [BoM Default-Fri3d_2020_Time_Blaster_00(Default).xls, BoM Default-Fri3d_2020_Time_Blaster_01(Default).xls, BoM USB-Fri3d_2020_Time_Blaster_00(USB).xls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]
2022-02-23 Rev. 02
    Added resistor for IR LEDs and block diagram of the blaster.
    [BoM Default-Fri3d_2020_Time_Blaster_02(Default).xls, BoM USB-Fri3d_2020_Time_Blaster_02(USB).xls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]
2022-07-09 Assembly notes added
    Added information regarding assembling the PCB
2022-07-09 Team switch info updated
    Added photo of team switch placement.
2022-07-18 Fixed resistor note, added LED polarity note
2022-08-02 updated grip design
    [Fri3d-TimeBlaster-Grip_v2.step, Fri3d-TimeBlaster-Grip_v2_Left.stl, Fri3d-TimeBlaster-Grip_v2_Right.stl]
2022-08-14 add LED Protector
    [Led_protector.scad, Led_protector.stl]
